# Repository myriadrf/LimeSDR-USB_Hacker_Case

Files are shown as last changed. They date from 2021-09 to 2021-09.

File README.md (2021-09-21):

# LimeSDR-USB Hacker Case

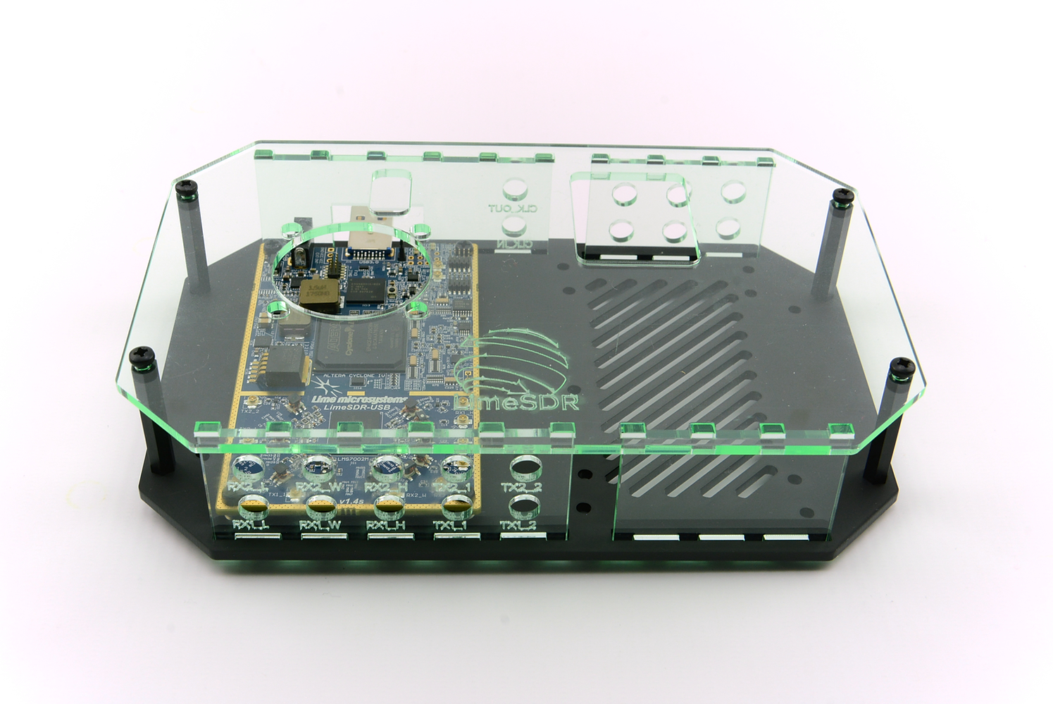
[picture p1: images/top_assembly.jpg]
LUHC-01 case


An acrylic enclosure designed to accommodate the LimeSDR-USB plus either a GPIO Board or LMS8001 Companion.

A complete kit of parts can be bought from [Crowd Supply](https://www.crowdsupply.com/lime-micro/limesdr).

## Repository contents

The case design is provided in the following formats:

* DXF

The case parts are laser cut from the following types of acrylic sheet:

* Base		: 3mm midnight black (frosted opaque)
* Sides & Top	: 3mm glass look (clear with green hue)

Other colours and finishes could be used, and the above were selected for a combination of aesthetic and practical reasons, e.g. frosted finish doesn't pick up finger marks.

## Bill of materials

In addition to the acrylic parts the kit contains:

| Qty | Item |
| --- | --- |
|  1  | 5VDC 40x40x10mm fan |
|  1  | 2-pin 0.1" male header |
|  4  | Self-tapping fans screws OR rubber fan mounts |
|  4  | 30mm black nylon M3 F-F hex spacers |
|  4  | M3x5 screws |
|  4  | 12mm black nylon M3 screws |
|  4  | Black nylon M3 nuts |
|  8  | Black steel M3 screws |
|  4  | Rubber bumpers |

## Other hardware required

- [LimeSDR-USB](https://myriadrf.org/projects/limesdr/)
- LimeSDR GPIO or LMS8001 Companion board
- Panel mount SMA socket to U.FL coaxial cables

## Assembly Guide

Please see the [assembly guide](ASSEMBLY.md)

## Changelog

| Version | Date | Summary |
|---|---|---|
| 1.1 | 01/09/2021 | v1.1 to accommodate LimeSDR with USB type A plug |
| 1.0 | 19/12/2017 | Initial version for LimeSDR with USB Type Micro B |

## Licence

LimeSDR-USB Hacker Case copyright 2017-2021 [AB Open Ltd](http://abopen.com).

<br />This work is licensed under a <a rel="license" href="http://creativecommons.org/licenses/by/4.0/">Creative Commons Attribution 4.0 International License</a>.

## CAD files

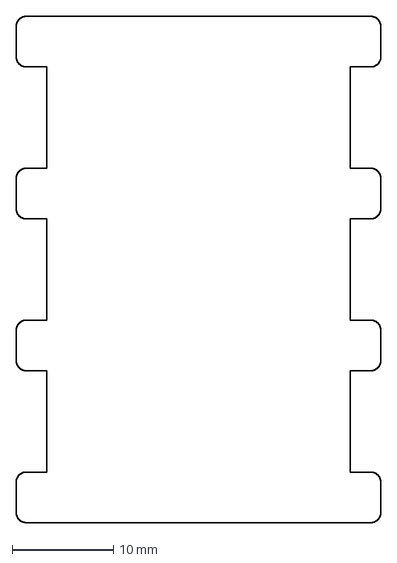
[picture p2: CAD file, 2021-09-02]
LUHC-01_Side_Solid.dxf
36.0 x 50.0 mm

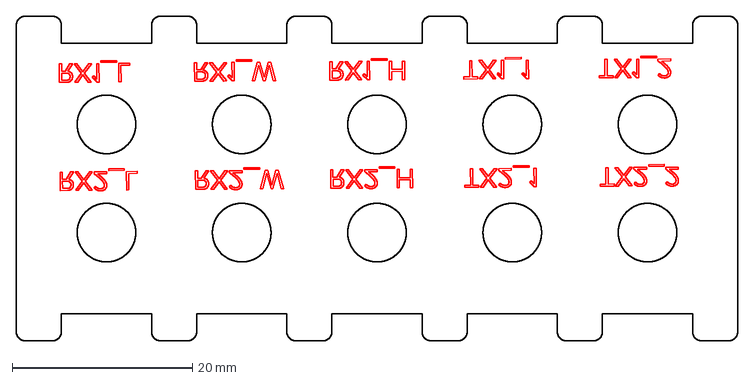
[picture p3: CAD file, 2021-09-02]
LUHC-01_Side_TXRX_SMA.dxf
80.0 x 36.0 mm

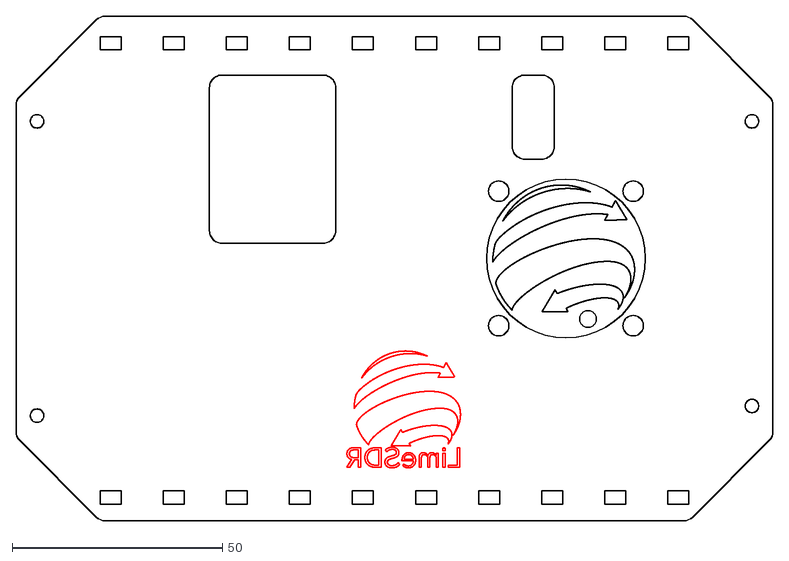
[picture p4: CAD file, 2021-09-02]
LUHC-01_Top.dxf
180.0 x 120.0

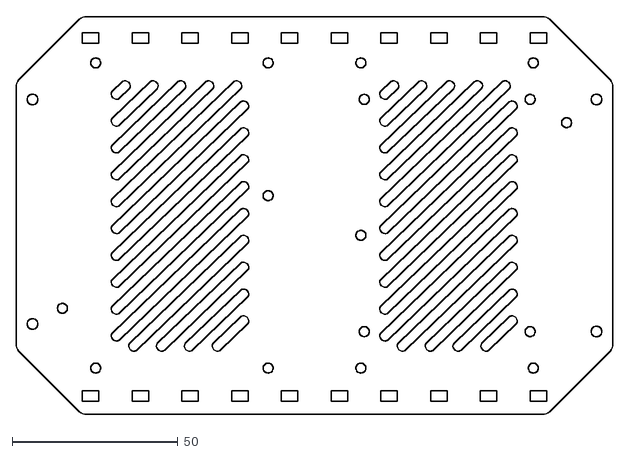
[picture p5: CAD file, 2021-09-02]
LUHC-01_Base.dxf
180.0 x 120.0

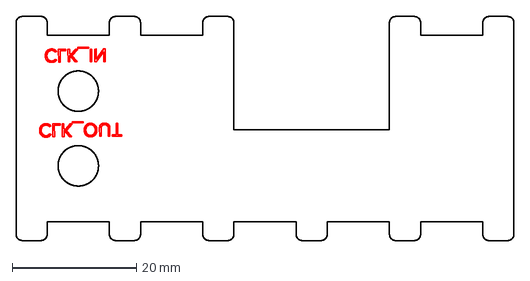
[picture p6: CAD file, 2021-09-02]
LUHC-01_Side_Slot_CLK_SMA.dxf
80.0 x 36.0 mm

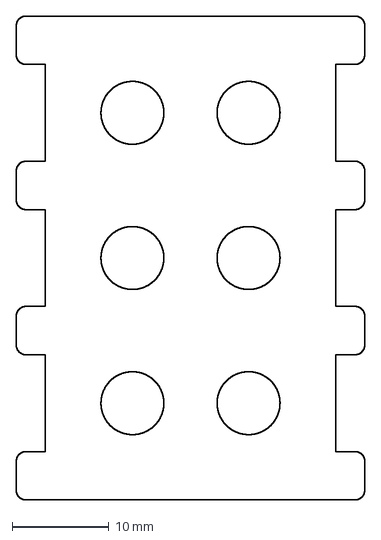
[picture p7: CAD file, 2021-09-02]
LUHC-01_Side_Extra_SMA.dxf
36.0 x 50.0 mm

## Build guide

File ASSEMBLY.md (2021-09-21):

# LimeSDR-USB Hacker Case Assembly Guide

This document outlines the assembly steps to successfully assemble your LimeSDR-USB Hacker Case.

## Steps

1. Check the kit contents - the contents of your kit should match the BOM listed in the repository README
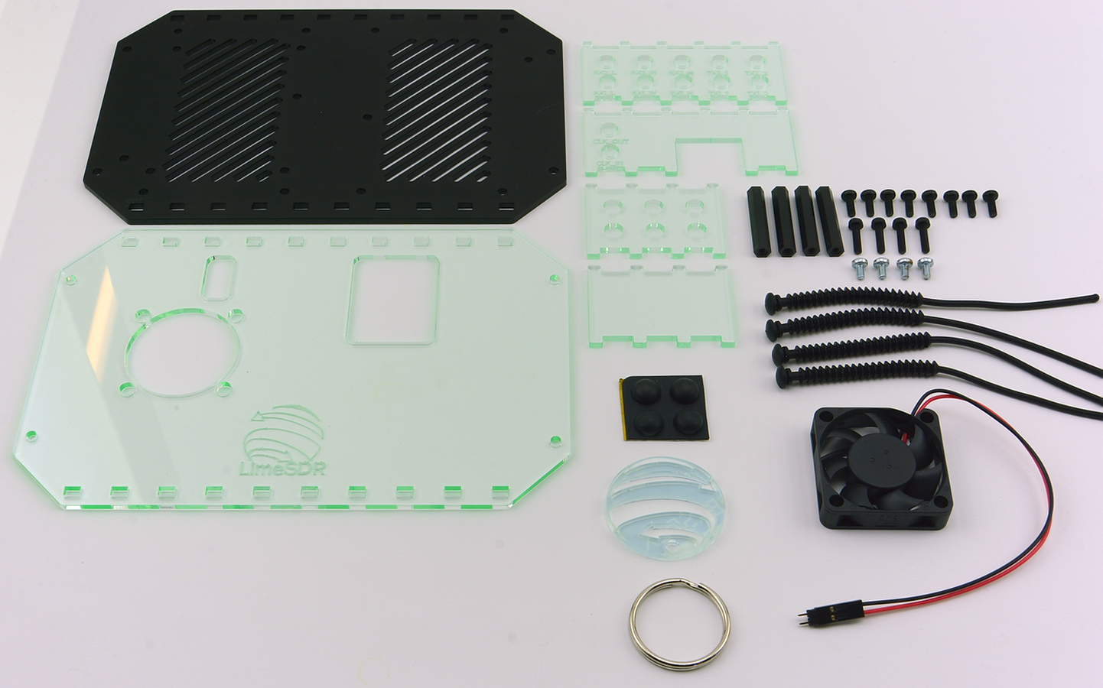
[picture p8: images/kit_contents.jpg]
Photo showing the LUHC kit contents laid out


2. Begin by securing 4x 30mm M3 threaded standoffs to the black base piece, using 4x black steel M3 screws
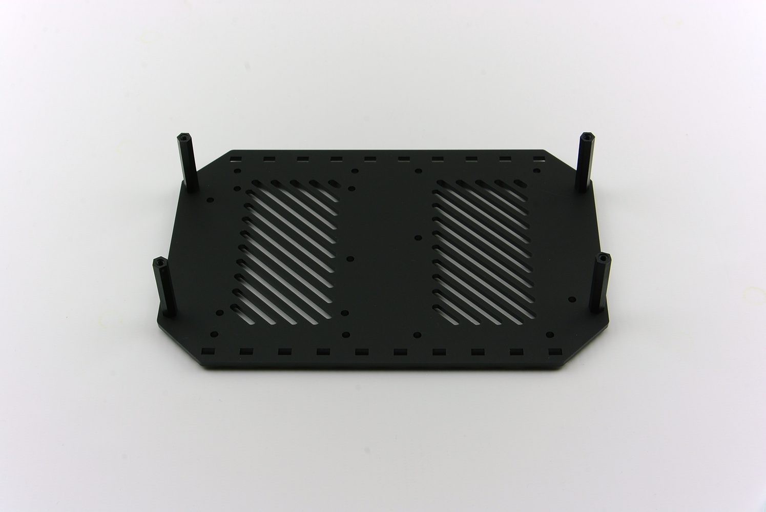
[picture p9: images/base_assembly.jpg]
Photo showing the black base piece with four threaded standoffs attached


3. Solder the two-pin fan header (included on the end of the fan lead) onto the LimeSDR-USB fan header J14 (located close to the U.FL antenna connections)
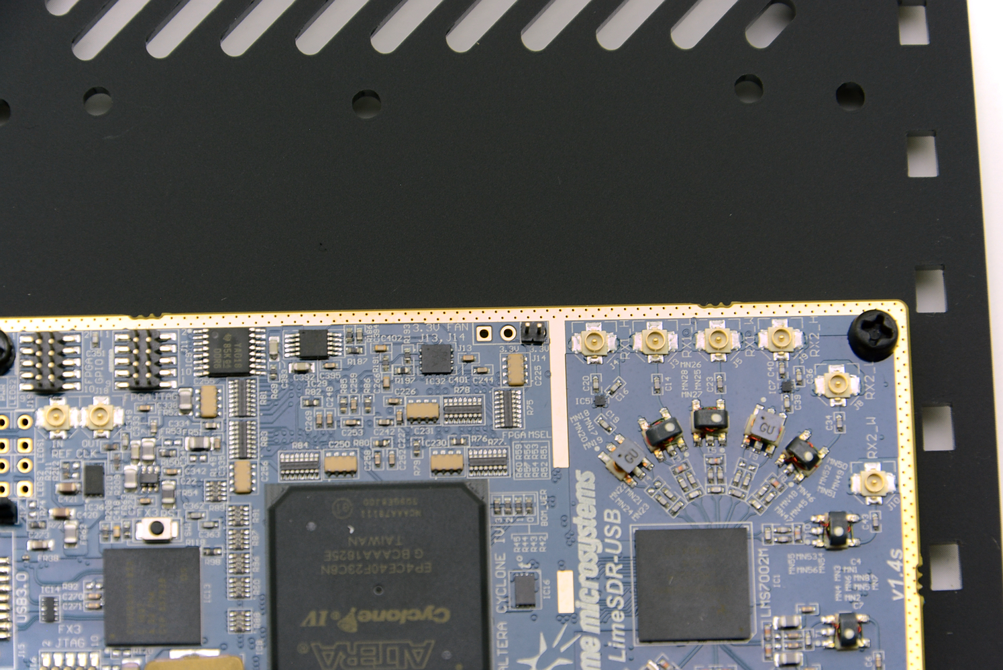
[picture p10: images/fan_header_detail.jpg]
Closeup photo showing the position of the J14 fan header


4. Fasten the fan to the top piece, using the four rubber barbed mounts
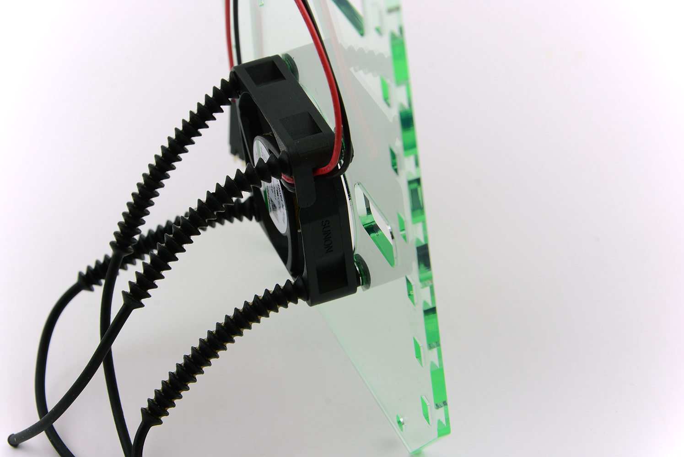
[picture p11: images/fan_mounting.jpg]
Photo showing the fan securely fastened to the top piece using rubber barbed mounts


5. Fasten the LimeSDR to the base piece using the four M3x5 screws & standoffs fastened to the LimeSDR PCB (Note: pliers might be helpful to hold the PCB standoffs stationary whilst tightening the screws)
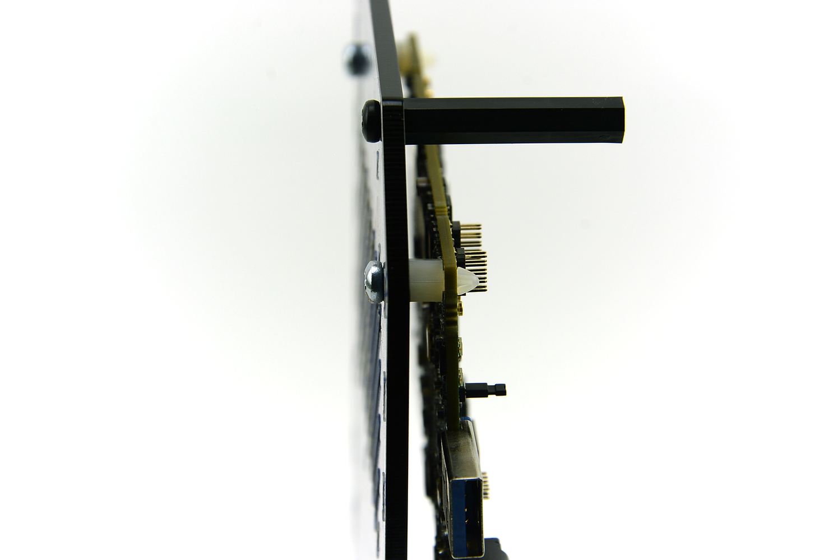
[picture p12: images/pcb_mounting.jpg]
Closeup photo showing the order of components to secure the LimeSDR to the base


6. Insert the four side panels so that the connectors line up with the LimeSDR connectors - at this point U.FL pigtails should also be fastened to the panels

7. Fasten the top piece to the threaded standoffs using the remaining 4x black steel M3 screws
Photo showing the complete case assembly, including LimeSDR

8. Stick the included 4x rubber bumpers to the bottom of the case

Assembly is now complete!

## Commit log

2017-12-12 Added source files for FreeCad + DXF
    [Lid.dxf, Mini_SMA_side.dxf, Mini_filled_side.dxf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]
2017-12-12 Renamed design files and deleted .bak files
    [LUHC-01.fcstd, LUHC-01_Base.dxf, LUHC-01_Side_Extra_SMA.dxf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]
2017-12-13 Updated DXF for base
    [LUHC-01.fcstd, LUHC-01_Base.dxf]
2017-12-19 Updated DXF files and added Inkcape .svg files
    Updated DXF files to a version that is compatible with Inkscape.
    Added Inkscape .svg versions of the files.
    Enlarged fan screw holes in the top to accomodate self tapping fan screws
    [LUHC-01_Base.dxf, LUHC-01_Side_Extra_SMA.dxf, LUHC-01_Side_Slot_CLK_SMA.dxf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]
2021-08-31 Add missing BOM for v1.0
2021-09-02 Updated design files
    Design files now updated to latest version. Updated documentation in README, and included ASSEMBLY.
    Remove old files
    - Removed FreeCAD file (only contained base plate)
    - Removed DXFs in preparation for regeneration
    [LUHC-01.fcstd, LUHC-01_Base.dxf, LUHC-01_Side_Extra_SMA.dxf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]
2021-09-02 Add images
    Fixed file name extensions to be lower case
2021-09-21 Update assembly guide, photos and BOM
    - Updated assembly guide to include note about using standoffs attached to LimeSDR PCB
    - Updated assembly guide photo to show detail of PCB standoff
    - Updated BOM to remove nylon nuts, screws and spacers in favour of M3x5 hardware
2021-09-27 Update kit_contents.jpg
    Updated photo to reflect current kit contents
2021-10-12 Create bag label
    Create bag label that includes link to GitHub repo with assembly instructions.
